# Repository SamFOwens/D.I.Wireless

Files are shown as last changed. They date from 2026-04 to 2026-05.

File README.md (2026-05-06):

# D.I.Wireless
We are using ring modulator mixers to transmit a message through magnetic fields. We use a function generator to create a 27kHz local oscillator frequency, and this LO is mixed with an audio message signal to create an amplitude modulated signal. This combined signal is used to vary the magnetic field in our transmitter coil. When the receiver coil is brought within close proximity of the transmitter coil, a magnetic field is induced within its windings which causes current to flow in the receiver coil. Sending the received signal through a ring modulator downconverts it back to the audio range. The downconverted signal then goes through a passive low pass filter and three amplifier stages before being sent into the speaker. We are using BJTs for power gain to drive the coils and op-amps to amplify the signals. All signals are generated using lab function generators. The transmitter and receiver coils are essentially an air-gapped transformer without a shared core.

Project Poster

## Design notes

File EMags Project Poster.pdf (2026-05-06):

# D.I.Wireless Power and Signal Transfer

## Melissa Burstein, David Green, Sam Owens

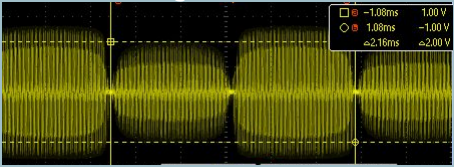
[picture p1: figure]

We wanted to build a circuit that uses magnetic fields to wirelessly transmit a signal, mimicking the telecoils in hearing aids. By modulating magnetic fields within two coils, we aimed to inductively transfer both power and signals through the air. We used concepts from our coursework in electromagnetism, solid state electronics, and communication systems to build this project. As a bonus, we set up our function generator for computer control and used this to create music.

## Abstract

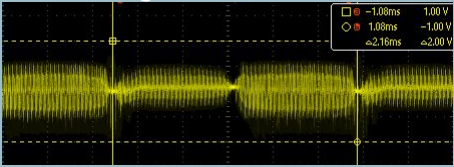
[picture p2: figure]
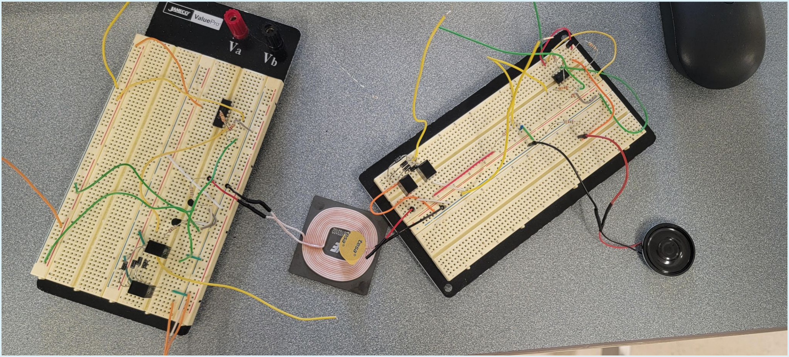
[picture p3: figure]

We are using ring modulator mixers to transmit a
message through magnetic fields. We use a function generator to create a 27kHz local oscillator frequency, and this LO is mixed with an audio message signal to create an amplitude modulated signal. This combined signal is used to vary the magnetic field in our transmitter coil. When the receiver coil is brought within close proximity of the transmitter coil, a magnetic field is induced within its windings which causes current to flow in the receiver coil. Sending the received signal through a ring modulator downconverts it back to the audio range. The downconverted signal then goes through a passive low pass filter and three amplifier stages before being sent into the speaker. We are using BJTs for power gain to drive the coils and op-amps to amplify the signals. All signals are generated using lab function generators. The transmitter and receiver coils are essentially an air-gapped transformer without a shared core.

## Design Concept

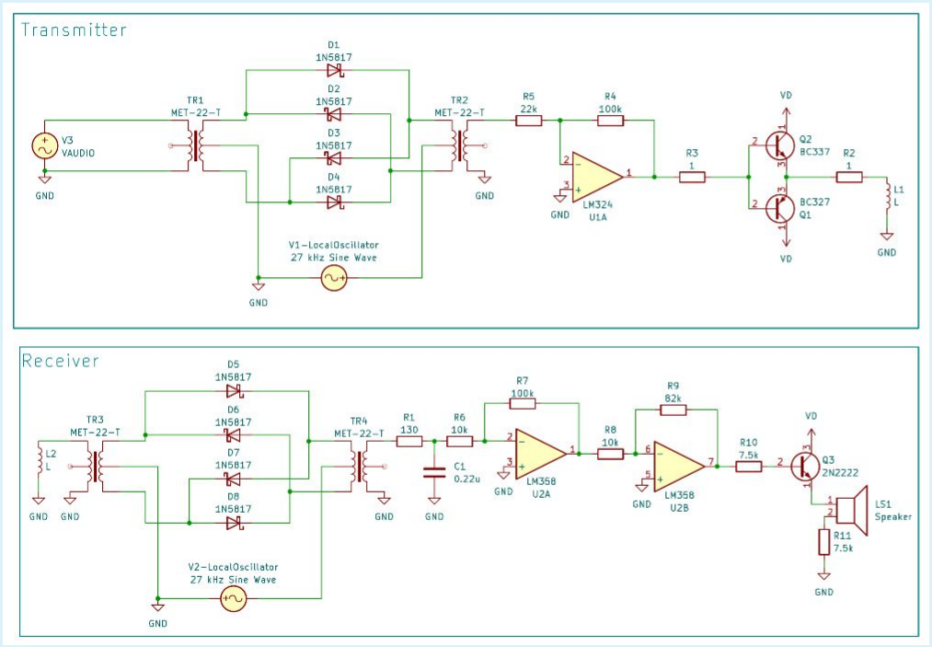
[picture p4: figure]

Step 1: We began by creating and simulating a theoretical design in LTSpice. The circuit was prototyped on a breadboard to allow for rapid troubleshooting of the oscillator and mixer stages.
Step 2: Using function generators and an oscilloscope, we tested our design and compared its performance against the simulation.

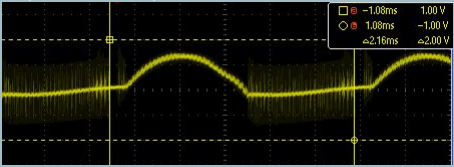
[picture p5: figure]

David: Circuit Build, Jukebox Program, Debugging Sam: Schematic Design, Circuit Build, Debugging Melissa: Circuit Build, Piano Program, KiCad

## Contribution

This project was a success! We were able to reach our goal of transmitting and receiving a signal using magnetic fields. We were unable to transmit as much power as we originally anticipated, but this wasn’t an issue as our project became more signal oriented and cooler anyway.

https://github.com/SamFOwens/D.I.Wireless

Step 3: During the testing phase, we realized that the signal was too weak to be picked up by the receiver. We decided to add an op-amp stage followed by a push/pull amplifier on the transmitter side to amplify the signal.
Step 4: Once the amplifiers were created, it was back to testing the signals to make sure they were high enough to drive a speaker, with 2 op-amp stages and an emitter follower right before the speaker. We experimented with a range of values to maximize our gain throughout the system.

## Testing and Validation

Understanding How Ring Modulators Produce AM Signals - Technical Articles (https://www.allaboutcircuits.com/technical-articles/understanding-how-ring-modulators-produce-am-signals/)

BJT Push-Pull explained - Electrical Engineering Stack Exchange (https://electronics.stackexchange.com/questions/535939/bjt-push-pull-explained)

## References

Speaker Output

Transmitted Signal

Received Signal

- Receiver and Transmitter coils
- 8 Schottky diodes
- 4 Center-Tapped Transformers
- BC337, BC327, 2N2222 Transistors

## Conclusion

## ECE 341, May 8, 2026

- LM358 and LM324 Operational Amplifiers
- Speaker (1W 8Ω)
- Resistors and Capacitors (assorted)
- Function Generators and DC Power Supply

## Implementation

## Technical Design

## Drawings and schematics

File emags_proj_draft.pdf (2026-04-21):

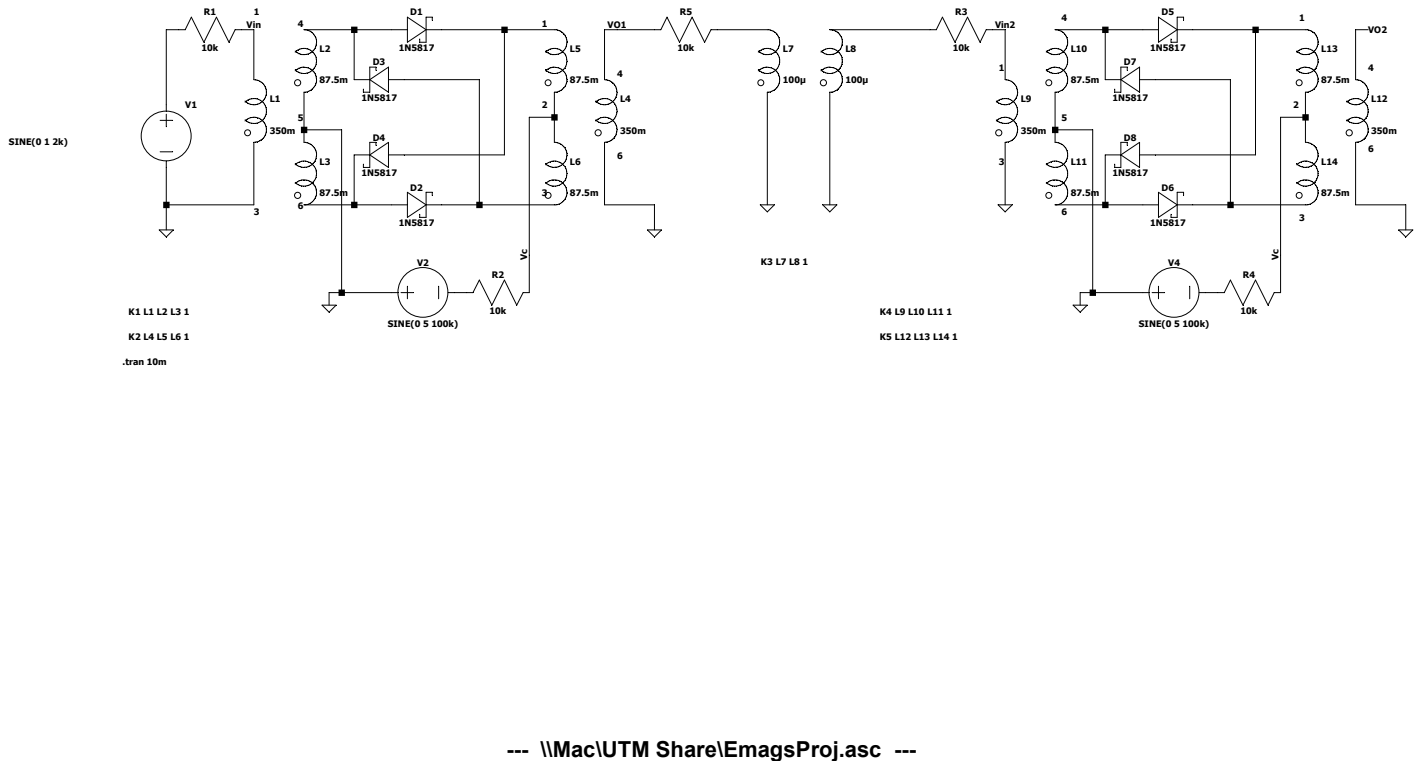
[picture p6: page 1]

--- \\Mac\UTM Share\EmagsProj.asc ---

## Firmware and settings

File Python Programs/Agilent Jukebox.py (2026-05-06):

import pyvisa
import time
import curses
import threading

# --- HARDWARE CONFIGURATION ---
MAX_VOLTAGE = 1.7            # Locked at 1.7Vpp
IMPEDANCE = "25"             # 25-ohm load
INAUDIBLE_FREQ = 1.0         # 1 Hz represents "silence"
OCTAVE_SHIFT = 1             # Transpose everything up 2 octaves
WAVEFORM = "SQUare"          # Square waves sound more like an ice cream truck
# ------------------------------

def midi_to_freq(note):
    """Converts a MIDI note number to Hz, applying an octave shift."""
    if note == 0: return INAUDIBLE_FREQ
    shifted_note = note + (OCTAVE_SHIFT * 12)
    return 440.0 * (2.0 ** ((shifted_note - 69) / 12.0))

# --- FULL SONG TRANSCRIPTIONS ---
# Format: (MIDI_Note, Note_Duration_Secs, Rest_After_Secs)
# 0 = Musical Rest

songs = {
    "Daisy Bell (Bicycle Built for Two)": [
        (79, 0.6, 0.1), (76, 0.6, 0.1), (72, 0.6, 0.1), (67, 0.6, 0.1), # Daisy, Daisy
        (69, 0.3, 0.05), (72, 0.3, 0.05), (69, 0.3, 0.05), (67, 0.4, 0.1), (64, 0.3, 0.05), (60, 0.8, 0.2), # Give me your answer do
        (62, 0.6, 0.1), (65, 0.6, 0.1), (69, 0.6, 0.1), (67, 0.6, 0.1), # I'm half crazy
        (64, 0.3, 0.05), (65, 0.3, 0.05), (67, 0.3, 0.05), (69, 0.4, 0.1), (62, 0.4, 0.1), (67, 0.8, 0.2), # All for the love of you
        (76, 0.4, 0.05), (74, 0.2, 0.05), (72, 0.3, 0.05), (69, 0.3, 0.05), (72, 0.4, 0.1), (69, 0.3, 0.05), (67, 0.3, 0.05), # It won't be a stylish marriage
        (60, 0.3, 0.05), (62, 0.3, 0.05), (64, 0.3, 0.05), (67, 0.3, 0.05), (69, 0.3, 0.05), (72, 0.3, 0.05), (69, 0.6, 0.1), # I can't afford a carriage
        (67, 0.4, 0.1), (72, 0.4, 0.1), (69, 0.4, 0.1), (67, 0.3, 0.05), (64, 0.3, 0.05), (60, 0.4, 0.1), # But you'll look sweet, upon the seat
        (62, 0.3, 0.05), (64, 0.3, 0.05), (67, 0.3, 0.05), (71, 0.3, 0.05), (72, 0.8, 0.4) # Of a bicycle built for two!
    ],
    "Mister Softee Theme (Full)": [
        (76, 0.2, 0.05), (72, 0.2, 0.05), (76, 0.2, 0.05), (72, 0.2, 0.05), (76, 0.2, 0.05), (72, 0.2, 0.05), (76, 0.4, 0.05),
        (79, 0.2, 0.05), (77, 0.2, 0.05), (74, 0.2, 0.05), (77, 0.2, 0.05), (74, 0.2, 0.05), (77, 0.2, 0.05), (74, 0.2, 0.05), (77, 0.4, 0.05),
        (77, 0.2, 0.05), (74, 0.2, 0.05), (77, 0.2, 0.05), (74, 0.2, 0.05), (77, 0.2, 0.05), (74, 0.2, 0.05), (77, 0.4, 0.05),
        (76, 0.2, 0.05), (72, 0.2, 0.05), (76, 0.2, 0.05), (72, 0.2, 0.05), (76, 0.2, 0.05), (72, 0.2, 0.05), (76, 0.4, 0.2)
    ],
    "Turkey in the Straw (Full A & B Part)": [
        (67, 0.2, 0.05), (67, 0.2, 0.05), (71, 0.2, 0.05), (67, 0.2, 0.05), (69, 0.2, 0.05), (67, 0.2, 0.05), (64, 0.2, 0.05), (62, 0.4, 0.05),
        (67, 0.2, 0.05), (67, 0.2, 0.05), (71, 0.2, 0.05), (67, 0.2, 0.05), (69, 0.2, 0.05), (71, 0.2, 0.05), (74, 0.6, 0.1),
        (74, 0.2, 0.05), (76, 0.2, 0.05), (74, 0.2, 0.05), (71, 0.2, 0.05), (69, 0.2, 0.05), (67, 0.2, 0.05), (64, 0.2, 0.05), (62, 0.4, 0.05),
        (67, 0.2, 0.05), (64, 0.2, 0.05), (62, 0.2, 0.05), (64, 0.2, 0.05), (67, 0.4, 0.05), (67, 0.6, 0.2)
    ],
    "Pop Goes the Weasel (Complete)": [
        (60, 0.3, 0.05), (60, 0.3, 0.05), (62, 0.3, 0.05), (62, 0.3, 0.05), (64, 0.2, 0.05), (67, 0.2, 0.05), (64, 0.2, 0.05), (60, 0.4, 0.1),
        (60, 0.3, 0.05), (60, 0.3, 0.05), (62, 0.3, 0.05), (62, 0.3, 0.05), (64, 0.6, 0.2),
        (60, 0.3, 0.05), (60, 0.3, 0.05), (62, 0.3, 0.05), (62, 0.3, 0.05), (64, 0.2, 0.05), (67, 0.2, 0.05), (64, 0.2, 0.05), (60, 0.4, 0.1),
        (69, 0.6, 0.1), (65, 0.4, 0.1), (64, 0.2, 0.05), (62, 0.2, 0.05), (60, 0.6, 0.4)
    ],
    "Yankee Doodle (Verse & Chorus)": [
        (60, 0.2, 0.05), (60, 0.2, 0.05), (62, 0.2, 0.05), (64, 0.2, 0.05), (60, 0.2, 0.05), (64, 0.2, 0.05), (62, 0.4, 0.1),
        (60, 0.2, 0.05), (60, 0.2, 0.05), (62, 0.2, 0.05), (64, 0.2, 0.05), (60, 0.2, 0.05), (59, 0.4, 0.1),
        (60, 0.2, 0.05), (60, 0.2, 0.05), (62, 0.2, 0.05), (64, 0.2, 0.05), (65, 0.2, 0.05), (64, 0.2, 0.05), (62, 0.2, 0.05), (60, 0.2, 0.05),
        (59, 0.2, 0.05), (55, 0.2, 0.05), (57, 0.2, 0.05), (59, 0.2, 0.05), (60, 0.4, 0.05), (60, 0.6, 0.2),
        (65, 0.3, 0.05), (64, 0.1, 0.05), (65, 0.2, 0.05), (67, 0.2, 0.05), (65, 0.4, 0.05), (64, 0.4, 0.05),
        (62, 0.3, 0.05), (64, 0.1, 0.05), (62, 0.2, 0.05), (60, 0.2, 0.05), (62, 0.4, 0.05), (64, 0.2, 0.05), (60, 0.2, 0.05)
    ],
    "London Bridge (Extended)": [
        (67, 0.3, 0.05), (69, 0.2, 0.05), (67, 0.2, 0.05), (65, 0.2, 0.05), (64, 0.2, 0.05), (65, 0.2, 0.05), (67, 0.4, 0.1),
        (62, 0.2, 0.05), (64, 0.2, 0.05), (65, 0.4, 0.1), (64, 0.2, 0.05), (65, 0.2, 0.05), (67, 0.4, 0.1),
        (67, 0.3, 0.05), (69, 0.2, 0.05), (67, 0.2, 0.05), (65, 0.2, 0.05), (64, 0.2, 0.05), (65, 0.2, 0.05), (67, 0.4, 0.1),
        (62, 0.4, 0.05), (67, 0.4, 0.05), (64, 0.2, 0.05), (60, 0.6, 0.2)
    ],
    "Oh! Susanna (Verse & Chorus)": [
        (60, 0.2, 0.05), (62, 0.2, 0.05), (64, 0.3, 0.05), (67, 0.3, 0.05), (67, 0.3, 0.05), (69, 0.2, 0.05), (67, 0.2, 0.05), (64, 0.2, 0.05), 
        (60, 0.3, 0.05), (62, 0.3, 0.05), (64, 0.2, 0.05), (64, 0.2, 0.05), (62, 0.2, 0.05), (60, 0.2, 0.05), (62, 0.6, 0.1),
        (60, 0.2, 0.05), (62, 0.2, 0.05), (64, 0.3, 0.05), (67, 0.3, 0.05), (67, 0.3, 0.05), (69, 0.2, 0.05), (67, 0.2, 0.05), (64, 0.2, 0.05), 
        (60, 0.3, 0.05), (62, 0.3, 0.05), (64, 0.2, 0.05), (64, 0.2, 0.05), (62, 0.2, 0.05), (62, 0.2, 0.05), (60, 0.8, 0.2),
        (65, 0.4, 0.05), (65, 0.4, 0.05), (69, 0.6, 0.05), (69, 0.4, 0.05), (67, 0.4, 0.05), (67, 0.2, 0.05), (64, 0.2, 0.05), (60, 0.6, 0.2)
    ],
    "Camptown Races (Full)": [
        (67, 0.3, 0.05), (67, 0.3, 0.05), (64, 0.2, 0.05), (67, 0.2, 0.05), (69, 0.4, 0.05), (67, 0.4, 0.05), (64, 0.6, 0.1),
        (62, 0.4, 0.05), (62, 0.4, 0.05), (64, 0.2, 0.05), (62, 0.2, 0.05), (60, 0.4, 0.1),
        (67, 0.3, 0.05), (67, 0.3, 0.05), (64, 0.2, 0.05), (67, 0.2, 0.05), (69, 0.4, 0.05), (67, 0.4, 0.05), (64, 0.6, 0.1),
        (62, 0.4, 0.05), (64, 0.2, 0.05), (62, 0.2, 0.05), (60, 0.6, 0.2)
    ],
    "The Entertainer (Full A-Section)": [
        (74, 0.15, 0.05), (75, 0.15, 0.05), (76, 0.15, 0.05), (84, 0.3, 0.1), (76, 0.15, 0.05), (84, 0.3, 0.1), (76, 0.15, 0.05), (84, 0.5, 0.1),
        (84, 0.15, 0.05), (83, 0.15, 0.05), (81, 0.15, 0.05), (79, 0.15, 0.05), (81, 0.15, 0.05), (79, 0.15, 0.05), (76, 0.15, 0.05), (77, 0.15, 0.05), (79, 0.6, 0.2),
        (74, 0.15, 0.05), (75, 0.15, 0.05), (76, 0.15, 0.05), (84, 0.3, 0.1), (76, 0.15, 0.05), (84, 0.3, 0.1), (76, 0.15, 0.05), (84, 0.5, 0.1),
        (79, 0.15, 0.05), (81, 0.15, 0.05), (83, 0.15, 0.05), (84, 0.15, 0.05), (86, 0.15, 0.05), (84, 0.15, 0.05), (81, 0.15, 0.05), (83, 0.15, 0.05), (84, 0.8, 0.2)
    ]
}

# --- THREADING & PLAYBACK LOGIC ---
stop_event = threading.Event()
current_thread = None

def smart_sleep(duration, stop_ev):
    end = time.time() + duration
    while time.time() < end:
        if stop_ev.is_set(): return False
        time.sleep(0.01)
    return True

def play_tune(agilent, song_name, stop_ev):
    melody = songs[song_name]
    while not stop_ev.is_set():
        for note, duration, rest in melody:
            if stop_ev.is_set(): break
            
            freq = midi_to_freq(note)
            agilent.write(f"FREQuency {freq:.3f}")
            if not smart_sleep(duration, stop_ev): break
            
            if rest > 0:
                agilent.write(f"FREQuency {INAUDIBLE_FREQ}")
                if not smart_sleep(rest, stop_ev): break
        
        if not stop_ev.is_set():
            agilent.write(f"FREQuency {INAUDIBLE_FREQ}")
            smart_sleep(1.5, stop_ev) # 1.5 second pause between loops

# --- CURSES TUI ---
def draw_menu(stdscr, agilent):
    global current_thread, stop_event
    curses.curs_set(0)
    stdscr.nodelay(1)
    curses.start_color()
    curses.init_pair(1, curses.COLOR_BLACK, curses.COLOR_CYAN)
    
    menu_items = list(songs.keys())
    current_row = 0
    playing_song = None

    while True:
        stdscr.erase()
        h, w = stdscr.getmaxyx()
        
        title = " 🍦 MR. AGILENT'S 8-BIT ICE CREAM TRUCK 🍦 "
        stdscr.addstr(1, w//2 - len(title)//2, title, curses.A_BOLD | curses.color_pair(1))
        
        status = f" Status: [{'PLAYING' if playing_song else 'STOPPED'}] {playing_song if playing_song else ''}"
        stdscr.addstr(3, 2, status, curses.A_BOLD)
        stdscr.addstr(4, 2, "-" * (w - 4))

        for idx, row in enumerate(menu_items):
            x = w//2 - len(row)//2
            y = h//2 - len(menu_items)//2 + idx
            if idx == current_row:
                stdscr.attron(curses.color_pair(1))
                stdscr.addstr(y, x, f" > {row} < ")
                stdscr.attroff(curses.color_pair(1))
            else:
                stdscr.addstr(y, x, f"   {row}   ")
                
        footer = "[UP/DOWN]: Select   [ENTER]: Play   [S]: Stop   [Q]: Quit"
        stdscr.addstr(h-2, w//2 - len(footer)//2, footer)
        
        stdscr.refresh()
        
        key = stdscr.getch()
        if key == curses.KEY_UP and current_row > 0:
            current_row -= 1
        elif key == curses.KEY_DOWN and current_row < len(menu_items)-1:
            current_row += 1
        elif key in [10, 13]: 
            if current_thread and current_thread.is_alive():
                stop_event.set()
                current_thread.join()
            stop_event.clear()
            playing_song = menu_items[current_row]
            current_thread = threading.Thread(target=play_tune, args=(agilent, playing_song, stop_event))
            current_thread.start()
        elif key in [ord('s'), ord('S')]:
            if current_thread and current_thread.is_alive():
                stop_event.set()
                current_thread.join()
            playing_song = None
            agilent.write(f"FREQuency {INAUDIBLE_FREQ}")
        elif key in [ord('q'), ord('Q')]:
            if current_thread and current_thread.is_alive():
                stop_event.set()
                current_thread.join()
            break
            
        time.sleep(0.05)

# --- MAIN EXECUTION ---
def main():
    rm = pyvisa.ResourceManager('@py')
    try:
        resources = rm.list_resources()
        usb_instruments = [res for res in resources if 'USB' in res]
        if not usb_instruments:
            print("No Agilent found. Check USB connection.")
            return
            
        agilent = rm.open_resource(usb_instruments[0])
        
        # Hardware Setup
        agilent.write("*RST")
        time.sleep(0.5)
        agilent.write(f"FUNCtion {WAVEFORM}") 
        agilent.write(f"OUTPut:LOAD {IMPEDANCE}")
        agilent.write(f"VOLTage {MAX_VOLTAGE}") 
        agilent.write(f"FREQuency {INAUDIBLE_FREQ}")
        agilent.write("OUTPut ON")
        
        curses.wrapper(draw_menu, agilent)
        
    except Exception as e:
        print(f"Hardware Error: {e}")
    finally:
        try:
            agilent.write("VOLTage 0.01")
            agilent.write("OUTPut OFF")
            agilent.close()
        except:
            pass

if __name__ == "__main__":
    main()

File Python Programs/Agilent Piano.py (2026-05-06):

import pyvisa
import tkinter as tk

# 1. Setup Connection
rm = pyvisa.ResourceManager('@py')
gen = rm.open_resource('USB0::2391::1031::MY44006981::0::INSTR')

# 2. Initial Config
gen.write('*RST')           
gen.write('OUTP:LOAD 25')  
gen.write('VOLT 1.5')       
gen.write('FUNC SIN')       
gen.write('OUTP ON')        

# 3. Define Note Map 
notes = {
    # White Keys
    'a': (246.94*4, 'B5'),
    's': (261.63*4, 'C6'),
    'd': (293.66*4, 'D6'),
    'f': (329.63*4, 'E6'),
    'g': (349.23*4, 'F6'),
    'h': (392.00*4, 'G6'),
    'j': (440.00*4, 'A6'),
    'k': (493.88*4, 'B6'),
    'l': (523.25*4, 'C7'),
    ';': (587.33*4, 'D7'), 
    "'": (659.25*4, 'E7'),
    
    # Black Keys
    'e': (277.18*4, 'C#6'),
    'r': (311.13*4, 'D#6'),
    'y': (369.99*4, 'F#6'),
    'u': (415.30*4, 'G#6'),
    'i': (466.16*4, 'A#6'),
    'p': (554.37*4, 'C#7'), 
    '[': (622.25*4, 'D#7')
}

# The visual order of keys
white_keys = ['a', 's', 'd', 'f', 'g', 'h', 'j', 'k', 'l', ';', "'"]
black_keys = {'e': 1, 'r': 2, 'y': 4, 'u': 5, 'i': 6, 'p': 8, '[': 9}

# 4. App Window Setup
root = tk.Tk()
root.title("Agilent 33220A Synth")
root.geometry("600x300") 
root.configure(bg="#2b2b2b") 

status_label = tk.Label(root, text="Click here first to play", font=("Helvetica", 16), fg="white", bg="#2b2b2b")
status_label.pack(pady=15)

canvas = tk.Canvas(root, width=550, height=200, bg="#2b2b2b", highlightthickness=0)
canvas.pack()

key_rects = {}
active_keys = {} 

# 5. The Press and Release Logic
def key_down(event):
    char = event.char.lower()
    if char in notes and not active_keys.get(char, False):
        active_keys[char] = True
        freq, note_name = notes[char]
        
        gen.write(f'FREQ {freq}')
        status_label.config(text=f"Playing: {note_name} | Freq: {freq} Hz")
        
        color = "#00ffff" if char in white_keys else "#0055ff"
        canvas.itemconfig(key_rects[char], fill=color)

def key_up(event):
    char = event.char.lower()
    if char in notes:
        active_keys[char] = False
        
        original_color = "white" if char in white_keys else "black"
        canvas.itemconfig(key_rects[char], fill=original_color)
        gen.write(f'FREQ 50')

# 6. Drawing the Piano Graphics
for i, char in enumerate(white_keys):
    x1 = i * 50
    x2 = x1 + 50
    rect = canvas.create_rectangle(x1, 0, x2, 200, fill="white", outline="black")
    key_rects[char] = rect

for char, pos in black_keys.items():
    x1 = (pos * 50) + 35 
    x2 = x1 + 30
    rect = canvas.create_rectangle(x1, 0, x2, 120, fill="black", outline="black")
    key_rects[char] = rect

# 7. Bind the computer keyboard to the app
root.bind('<KeyPress>', key_down)
root.bind('<KeyRelease>', key_up)

# 8. Safe Shutdown
def on_closing():
    print("Shutting down output...")
    gen.write('OUTP OFF')
    gen.close()
    root.destroy() 

root.protocol("WM_DELETE_WINDOW", on_closing)

# Run App
root.mainloop()

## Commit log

2026-05-04 final spice, with 25 ohm load resistance from function gens
2026-05-06 KiCad Schematic
    [DI Wireless Schematic.kicad_pcb, DI Wireless Schematic.kicad_sch]
2026-05-06 Final Schematic
    [DI Wireless Schematic.kicad_sch]
2026-05-07 fixed voltage rails on schematic
    [DI Wireless Schematic.kicad_sch]
